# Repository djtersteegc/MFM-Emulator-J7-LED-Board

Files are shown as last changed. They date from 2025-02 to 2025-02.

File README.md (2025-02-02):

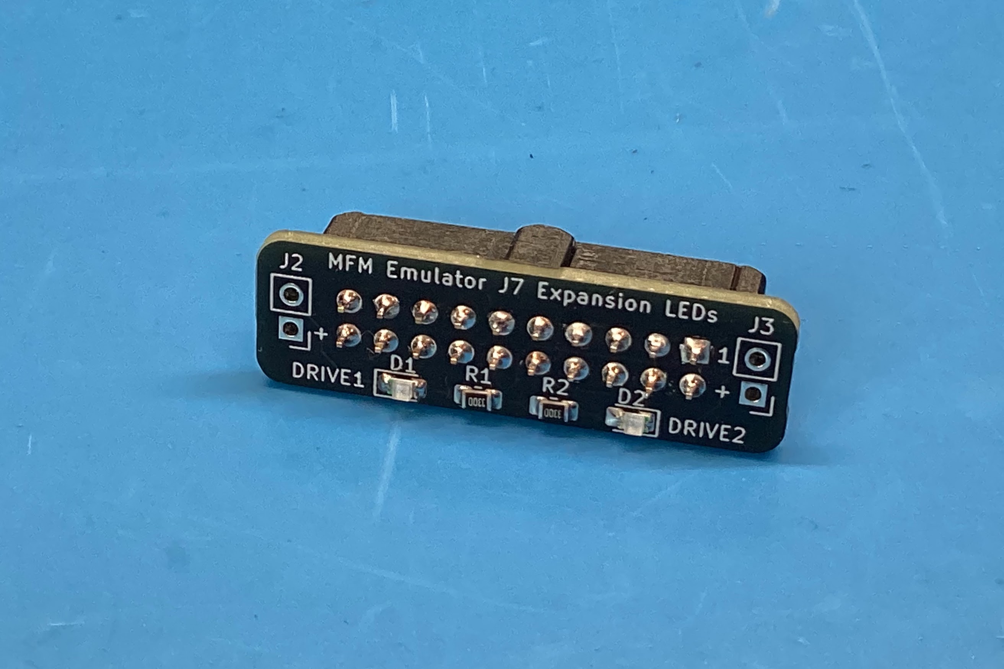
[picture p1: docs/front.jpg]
front


Simple PCB for the Drive 1 and Drive 2 select LED's exposed on the J7 expansion connector of [David Gesswein's MFM emulator](https://www.pdp8online.com/mfm/).  Plugs directly into the connector and uses 0805 SMD components for easier hand soldering.

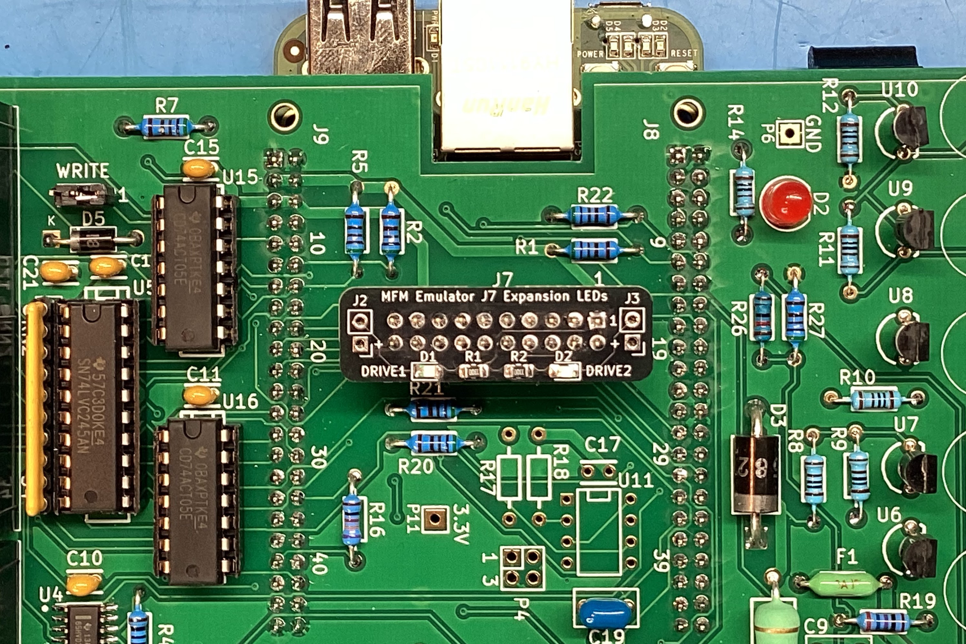
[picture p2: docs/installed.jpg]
installed


I used 330R resistors which were plenty bright with the green LED's. Just make sure to limit current to no more than 6ma since these are driven right from the BeagleBone GPIO's. You can also use the board as a breakout to pin headers and install external LED's instead of the SMD mounted ones.

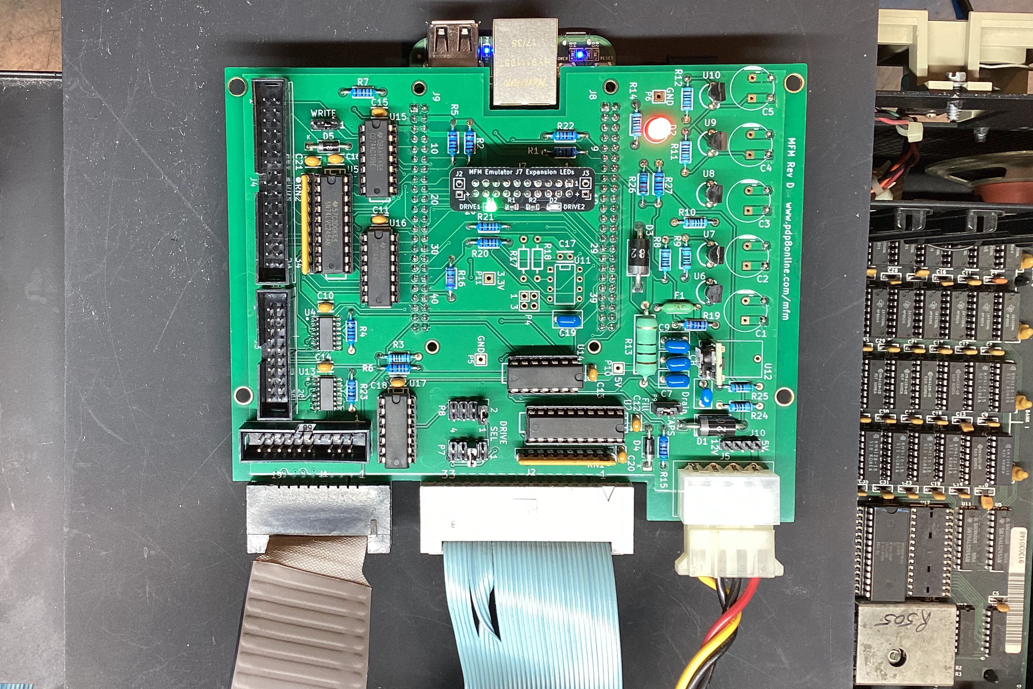
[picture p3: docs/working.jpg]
working


If you have a 3D printer, I also included a keyed sleeve that slides over a standard 2x10 2.54mm female pin socket and prevents you from potentially misaligning the board by one pin in the male IDC box socket.

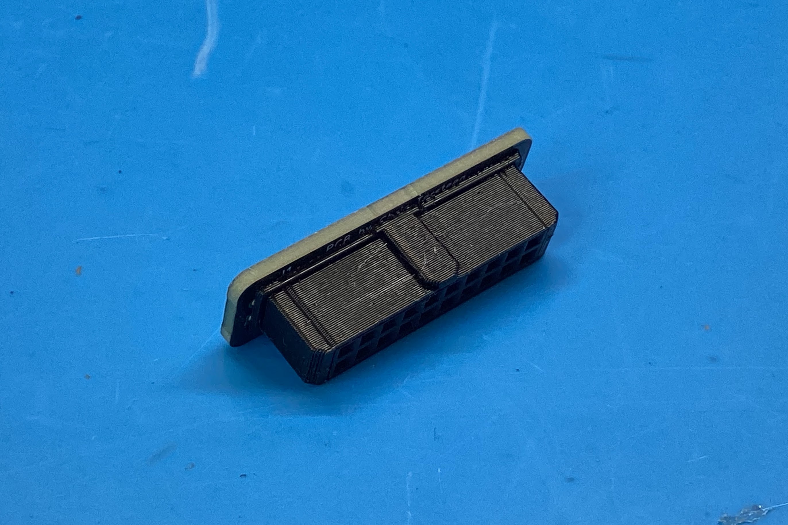
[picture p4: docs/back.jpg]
back


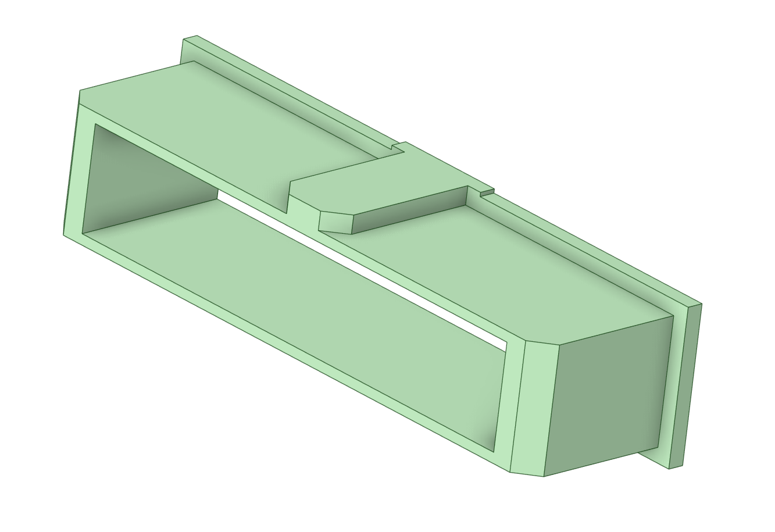
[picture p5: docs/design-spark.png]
design-spark


### BOM

https://djtersteegc.github.io/MFM-Emulator-J7-LED-Board/ibom-v1.0.html

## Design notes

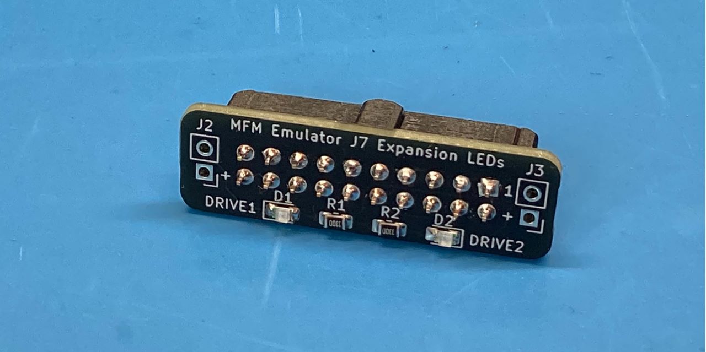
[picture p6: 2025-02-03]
docs/social.jpg

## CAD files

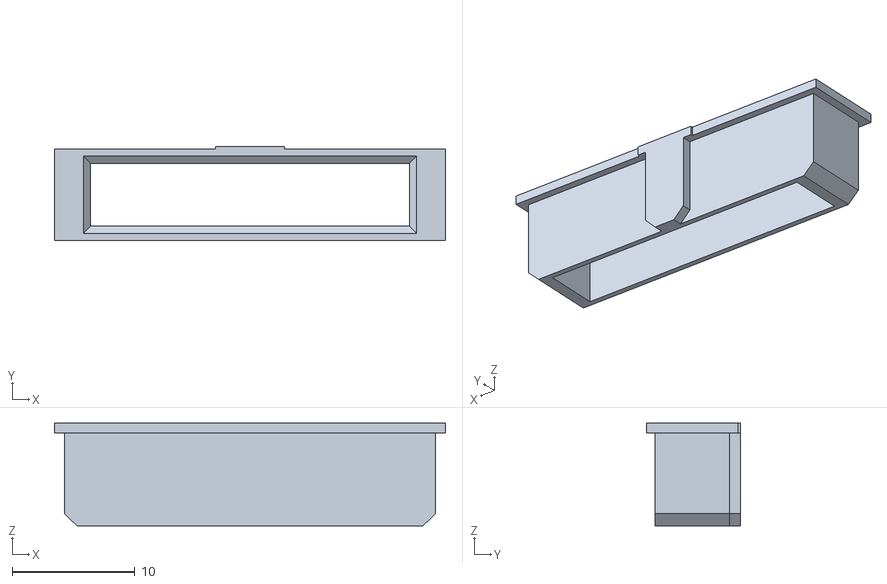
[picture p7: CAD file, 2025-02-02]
3D/STL/2x10 Female Header Sleave.stl
31.9 x 7.70 x 8.40

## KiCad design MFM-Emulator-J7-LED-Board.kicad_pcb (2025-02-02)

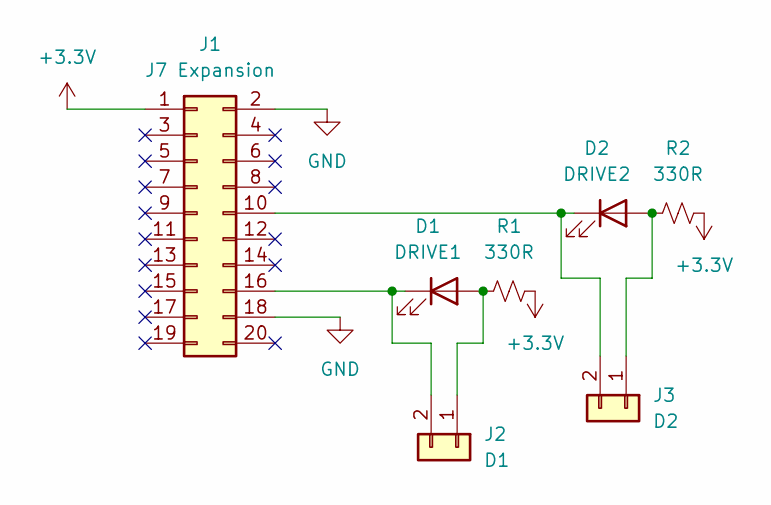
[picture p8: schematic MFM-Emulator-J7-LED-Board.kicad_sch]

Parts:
D1: DRIVE1; LED_0805_2012Metric_Pad1.15x1.40mm_HandSolder
D2: DRIVE2; LED_0805_2012Metric_Pad1.15x1.40mm_HandSolder
J1: J7 Expansion; PinSocket_2x10_P2.54mm_Vertical
J2: D1; PinHeader_1x02_P2.54mm_Vertical
J3: D2; PinHeader_1x02_P2.54mm_Vertical
R1, R2: 330R; R_0805_2012Metric_Pad1.20x1.40mm_HandSolder

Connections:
+3.3V: J1.1, R1.2, R2.2
GND: J1.2, J1.18
unnamed: D1.2 (A), J2.1, R1.1
unnamed: D1.1 (K), J1.16, J2.2
unnamed: D2.2 (A), J3.1, R2.1
unnamed: D2.1 (K), J1.10, J3.2

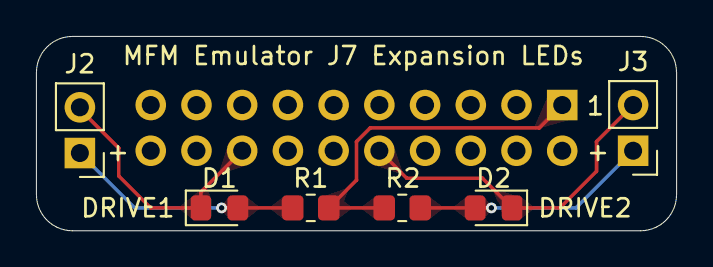
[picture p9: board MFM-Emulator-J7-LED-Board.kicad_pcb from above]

Board: 2 copper layers, 35.6 x 10.8 mm, 7 parts (1 on the bottom side), 6 nets.
